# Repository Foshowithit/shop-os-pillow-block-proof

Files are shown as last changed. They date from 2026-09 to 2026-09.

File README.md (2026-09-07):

# Shop OS — Pillow-Block Proof

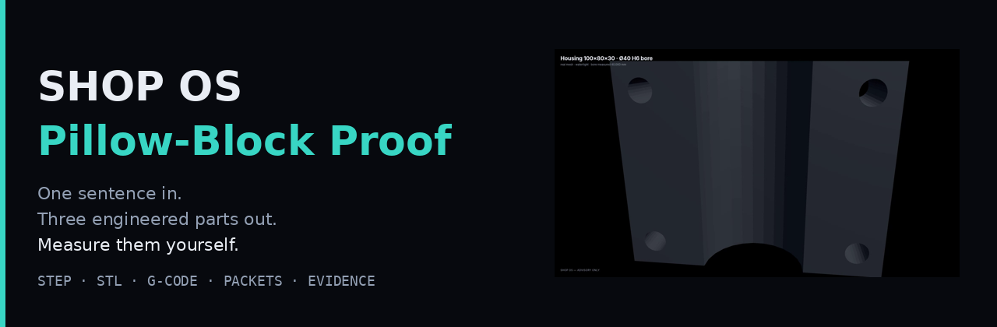
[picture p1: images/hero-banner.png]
Shop OS — Pillow-Block Proof


  

One sentence in. Three engineered parts out. **Measure them yourself.**

> Full run (28 s): one click → agent run → live interactive 3D part card in chat.
> Watch: [shopos-hero-28s.mp4](https://github.com/Foshowithit/shop-os-pillow-block-proof/releases/download/v1.0-proof/shopos-hero-28s.mp4)

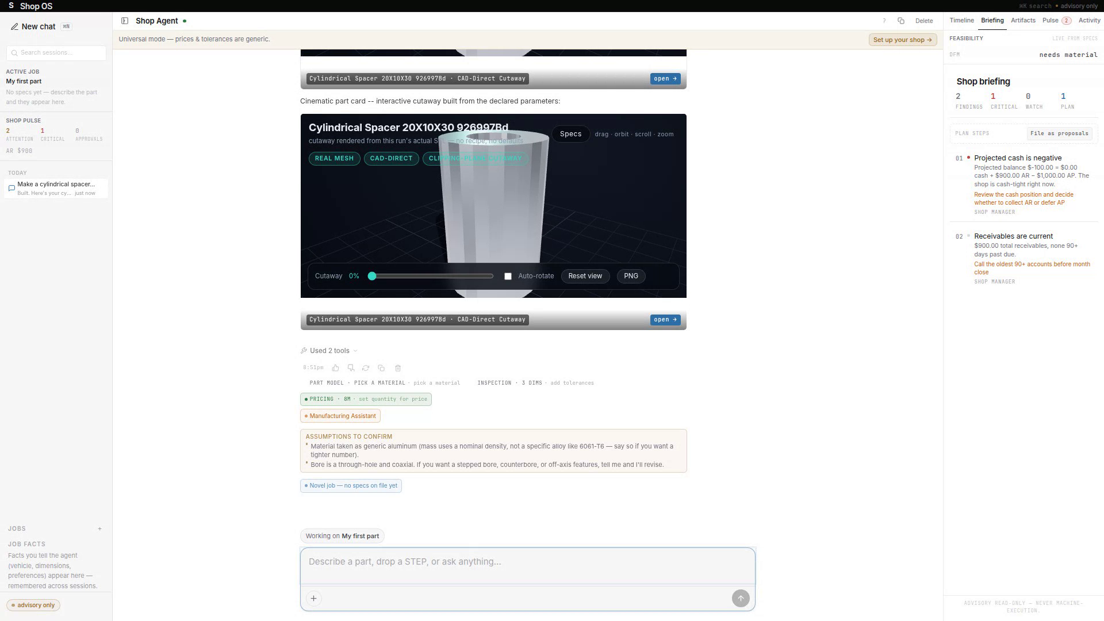
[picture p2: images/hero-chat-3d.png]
Live 3D part card inside the chat


> Full arc (78 s): run → housing orbit → spacer cutaway.
> Watch: [pillow-block-78s.mp4](https://github.com/Foshowithit/shop-os-pillow-block-proof/releases/download/v1.0-proof/pillow-block-78s.mp4)

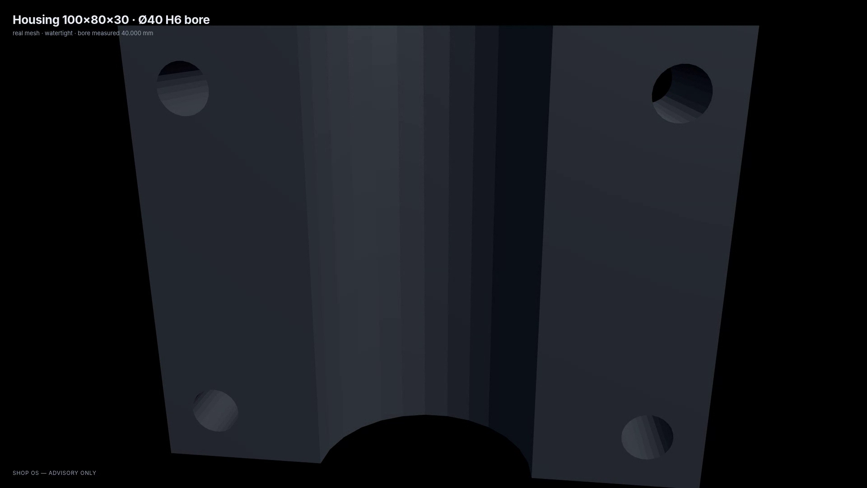
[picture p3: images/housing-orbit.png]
Housing 100×80×30, Ø40 H6 bore, orbiting


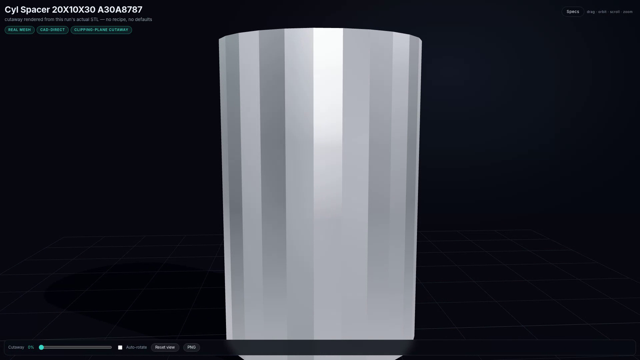
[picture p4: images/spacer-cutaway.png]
Spacer clipping-plane cutaway on the real mesh

> Beauty pass (30 s): orbit + cutaway.
> Watch: [shopos-card3d-30s.mp4](https://github.com/Foshowithit/shop-os-pillow-block-proof/releases/download/v1.0-proof/shopos-card3d-30s.mp4)

A shop agent takes a part description, engineers it (CAD, DFM, toolpaths,
verification), and hands you files — not renders. This repo is the receipts
from one real run: a pillow-block bearing unit (housing + cap + base plate).

## Watch

| Video | What |
|---|---|
| [shopos-hero-28s.mp4](https://github.com/Foshowithit/shop-os-pillow-block-proof/releases/download/v1.0-proof/shopos-hero-28s.mp4) | One click → agent run → live interactive 3D part card inside the chat (28 s) |
| [pillow-block-78s.mp4](https://github.com/Foshowithit/shop-os-pillow-block-proof/releases/download/v1.0-proof/pillow-block-78s.mp4) | Full arc: run → housing orbit → spacer cutaway (78 s) |
| [shopos-card3d-30s.mp4](https://github.com/Foshowithit/shop-os-pillow-block-proof/releases/download/v1.0-proof/shopos-card3d-30s.mp4) | Pure 3D: orbit + clipping-plane cutaway on the real mesh (30 s) |

## Measure it yourself

| File | Verification (independently re-measured) |
|---|---|
| `models/housing.step` / `.stl` | Open CASCADE 7.9 AP214 · 500 facets · watertight · bbox 100×80×30 · bore Ø40.000 |
| `models/cap.step` / `.stl` | 500 facets · watertight · groove Ø40.000 |
| `models/base_plate.step` / `.stl` | 876 facets · watertight · 120×100×12 |
| `programs/bore_h6_advisory.nc` | 113 blocks; parses clean; simulated — 36,224 voxels removed (1 mm grid) |
| `programs/drill_9mm.nc` | 11 blocks, 4×Ø9 pattern; simulated — 5,584 voxels removed |
| `programs/tap_m8.nc` | 14 blocks, M8×1.25 tapping w/ pitch check; simulated — 2,792 voxels removed |
| `programs/BLOCK-receipt.json` | Our own validator **refused** the naive end-mill-only Ø40 H6 plan |
| `programs/PASS-receipt.json` | Corrected bore+hone+CMM plan passes, hazard honestly still flagged |
| `verifiers/verify_pillow_block.py` | Runnable mesh verifier — `python verifiers/verify_pillow_block.py` from a clean clone |
| `validators/validate_tolerance_risk.py` | Runnable **manufacturing-plan risk linter** — reproduces BLOCK (exit 1) / PASS (exit 0) from public job cards |
| `validators/REPRODUCE.md` | Exact clean-clone commands and expected output |
| `packets/` | Per-part DFM packets + assembly manifest — every number reproduced; estimates labeled as estimates |

## Evidence class

- **Geometry-verified:** the three STL meshes pass the published watertight/bounding-box/bore verifier.
- **Process-reviewed:** the public RUE-019 manufacturing-plan linter reproduces the BLOCK→PASS verdicts.
- **Strategy-simulated:** the advisory NC programs are parser/stock-simulation inputs; they are **not** posted CAM, machine-kinematics verified, or production-approved.
- **Not yet proven:** machine capability, postprocessor output, physical machining, CMM/metrology, bearing selection from a cited catalog, and a production design load case.

## The honest flex

Most demos show success paths. Ours shows the system catching itself: the
naive bore plan gets BLOCKed with reasons, re-simulated as proof, and only
the corrected plan ships. Independently reviewed file-by-file — verdict: legit.

> ⚠️ **ADVISORY ONLY — NOT FOR MACHINE EXECUTION.** Every program, packet,
> and receipt here is engineering output for human review. Nothing runs on a
> controller without a qualified machinist's sign-off.

MIT License — files are yours to open, measure, cut (after review), and post about.

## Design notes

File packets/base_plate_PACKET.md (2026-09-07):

# Part Packet — Base Plate (pillow-block mounting plate)

_ADVISORY ONLY — machine_execution=false. No controller connection. No production authorization. Qualified machinist review required. No costs are stated in this packet (none computed). No cycle times are stated (none computed)._

## What this part is

Flat mounting plate the housed bearing bolts to: 120 × 100 × 12 slab
with four Dia 9 corner mounting holes and two M8×1.25 tapped holes.
No tight-tolerance bore on this part — general tolerance ±0.1 governs.

## Measured geometry (programmatic, not eyeballed)

Source: `verify_pillow_block.py` run 2026-09-07 — ALL PASS.

| Attribute | Measured |
|---|---|
| Envelope (bbox) | 120.00 × 100.00 × 12.00 mm |
| Mesh | watertight=True, 876 facets |
| Mesh volume | 138,586.7 mm³ (mesh volume, not weighed) |

Files: `base_plate.step` (44,473 B), `base_plate.stl` (43,884 B).

Note: the verifier checks envelope/watertight only for this part (no
bore feature). Hole diameters and positions below are program-stated,
not mesh-measured.

## DFM notes

- Straightforward 2.5D plate work: face, drill, tap. No validator
  hazard on this part (the H6/Ra-0.8 hazard lives on the housing/cap
  bore, not here).
- 12 mm plate in pre-hardened 4140 (job-spec material context): clamp
  flat, watch for movement after breaking the skin — shop practice,
  machinist to confirm.
- Tapped M8×1.25 in 12 mm plate gives ~9–10 mm thread engagement:
  adequate for a mounting plate, verify against the actual bolt loads
  (engineering check, not computed here).

## Process routing (plain English)

- `programs/drill_9mm.nc`: four Dia 9 corner holes at 15 mm insets
  (15,15 / 105,15 / 15,85 / 105,85), canned G81 cycle, Z−2 through,
  R14 retract. Positions are stated in the program header as an
  engineering assumption — confirm against the mating footprint.
- `programs/tap_m8.nc`: two M8×1.25 holes at (30,50) and (90,50) —
  Dia 6.8 drill (G81) then G84 tap at S800. Positions likewise assumed;
  confirm before cutting.

## Assumptions (estimates, not verified facts)

- All six hole positions are program-header assumptions, explicitly
  marked "(positions assumed - engineering assumption)" in the .nc
  files. They are not measured from the mesh and not approved.
- What the drill/tap programs IS: strategy/sequence proofs (hole order,
  canned cycles, tap pitch consistency), verified in sim (holes clear,
  lands kept, in-envelope SHIP). What they are NOT: posted, proven CAM
  — no post-processor ran and no machine kinematics were checked.
- Feeds/speeds (F180/F150/F1000, S800/S1200/S1500) are reference values;
  prove on the machine.

## Verification

- Geometry: `verify_pillow_block.py` PASS (watertight, bbox exact).
- Holes: program text reviewed only; hole callouts are NOT mesh-verified.

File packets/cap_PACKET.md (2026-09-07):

# Part Packet — Cap (pillow-block top half)

_ADVISORY ONLY — machine_execution=false. No controller connection. No production authorization. Qualified machinist review required. No costs are stated in this packet (none computed). No cycle times are stated (none computed)._

## What this part is

Upper half of the pillow-block housing. Mirrors the housing saddle with
a matching Dia 40 groove so the closed assembly traps the bearing race.
Same job spec family as the housing (4140 pre-hardened context,
general tolerance ±0.1 unless noted).

## Measured geometry (programmatic, not eyeballed)

Source: `verify_pillow_block.py` run 2026-09-07 — ALL PASS.

| Attribute | Measured |
|---|---|
| Envelope (bbox) | 100.00 × 80.00 × 20.00 mm |
| Groove diameter | 40.000 mm (span X 39.988, 28 bore-surface verts) |
| Mesh | watertight=True, 500 facets |
| Mesh volume | 106,759.3 mm³ (mesh volume, not weighed) |

Files: `cap.step` (37,360 B), `cap.stl` (25,084 B).

## Meshing note (from the verifier, factual)

The groove tool center sits 0.5 below the mating face (0.5 blind cover):
a nominal R20-on-20-thick tangency is a zero-thickness kiss that cannot
triangulate watertight. Groove diameter stays exactly 40.0; only the
cover overlap changed. This is a mesh-construction fact, not a design
change — the mating interface still closes on the housing saddle.

## DFM notes (grounded in validator receipts)

- The cap groove forms the top half of the Dia 40 H6 bore: same
  0.016 mm band + Ra 0.8 hazard as the housing (see housing packet and
  rue019 receipts). Same required controls apply — multi-pass,
  tolerance-capable tooling, runout budget, hone, CMM.
- Mating faces (cap-to-housing split line) must be flat and clean or
  the assembled bore distorts: face-mill both halves' split faces in
  the same setup family where possible (shop practice, machinist to
  confirm — not validator-stated).

## Process routing (plain English)

Same saddle program family as the housing
(`programs/bore_h6_advisory.nc` pattern: rough r=19.0 → semi r=19.7 →
finish r=20.0 → spring pass → hone → CMM), mirrored to the cap's 20 mm
thickness. What that program IS: a strategy/sequence proof (see housing
packet). What it is NOT: posted, proven CAM for the cap — no separate
cap program exists in `programs/`, and none is claimed here.

## Assumptions (estimates, not verified facts)

- Cap bolt circle / bolt sizes are not modeled and not specified: the
  cap-to-housing and cap-to-base fastening scheme is open engineering.
- Feeds/speeds, if reused from the housing program, are reference
  values; prove on the machine.

## Verification

- Geometry: `verify_pillow_block.py` PASS line (groove 40.000, span
  39.988 within the 0.6 mesh tolerance).
- Tolerance planning: inherits the rue019-corrected PASS approach;
  cap-specific validator run is open work, not claimed here.

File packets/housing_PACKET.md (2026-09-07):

# Part Packet — Housing (pillow-block saddle)

_ADVISORY ONLY — machine_execution=false. No controller connection. No production authorization. Qualified machinist review required. No costs are stated in this packet (none computed). No cycle times are stated (none computed)._

## What this part is

Lower half of a two-piece pillow-block bearing housing. A semicircular
saddle groove (nominal Dia 40 along the Y axis) cradles the bearing outer
race; the cap closes it from above. Material per job spec: 4140 alloy
steel, pre-hardened. General tolerance ±0.1 unless noted.

## Measured geometry (programmatic, not eyeballed)

Source: `verify_pillow_block.py` run 2026-09-07 — ALL PASS.

| Attribute | Measured |
|---|---|
| Envelope (bbox) | 100.00 × 80.00 × 30.00 mm |
| Saddle groove diameter | 40.000 mm (span X 40.000, 28 bore-surface verts) |
| Groove axis | X=50, Z=30, along Y, length 0–80 |
| Mesh | watertight=True, 500 facets |
| Mesh volume | 182,662.4 mm³ (mesh volume, not weighed) |

Files: `housing.step` (37,242 B), `housing.stl` (25,084 B).

## Critical feature — Dia 40 H6 bore

Spec (both rue019 job.yamls): diameter 40.0, +0.016/−0.000 (H6),
surface finish Ra 0.8. Tolerance band 0.016 mm — under the validator's
0.050 mm tight-band threshold — so this bore is the assembly's
tolerance hazard. See `rue019-block/` vs `rue019-corrected/` receipts
and the bore story in `ASSEMBLY.md`.

## DFM notes (grounded in validator receipts)

- A standard drill/ream cycle cannot hold H6 at 0.016 mm band + Ra 0.8
  (rue019-block BLOCK: "the card lacks a complete process response").
- Required, per receipt: multi-pass plan (rough → semi-finish → finish,
  spring pass optional), tolerance-capable tooling (fine boring head /
  adjustable reamer / honing — never a standard reamer without a
  capability check), runout budgeted against the 0.016 band, finish
  passes planned to Ra 0.8, CMM qualification.
- Saddle is an open half-round milled from above (not a closed bore):
  the corrected plan answers with profile passes + hone to size.

## Process routing (plain English)

Program `programs/bore_h6_advisory.nc` (advisory reference only):
 What this program IS: a strategy and sequence proof — the pass order,
 tool choices, and geometry a bore+hone+CMM plan needs, verified in sim
 (groove clears, stock kept, in-envelope SHIP).
 What it is NOT: posted, proven CAM. No post-processor ran, no machine
 kinematics were checked, feeds/speeds are reference values.
 datum is the housing base (Z0) with the X0Y0 corner; tools T1 D12 flat
 rougher and T2 D6 ball finisher. Four lanes across Y (10/30/50/70) cut
 the groove in three radii — rough r=19.0, semi r=19.7, finish r=20.0 —
 then a slow spring pass repeats the finish lane at Y40. To size means
 hone Dia 40 holding the 0.016 band, then CMM-qualify bore diameter
 (true position: none on this job).

## Assumptions (estimates, not verified facts)

- Stock 100×80×30 and 4140 pre-hardened come from the job spec, not from
  measurement of bar stock.
- Feeds/speeds in the .nc (F240/F120, S3000) are reference values from
  the advisory program; prove them on the machine, do not trust them.

## Verification

- Geometry: `verify_pillow_block.py` PASS line quoted above.
- Tolerance planning: rue019-corrected PASS (`response.adequate: true`,
  `missing: []`); the naive variant honestly BLOCKs (see ASSEMBLY.md).

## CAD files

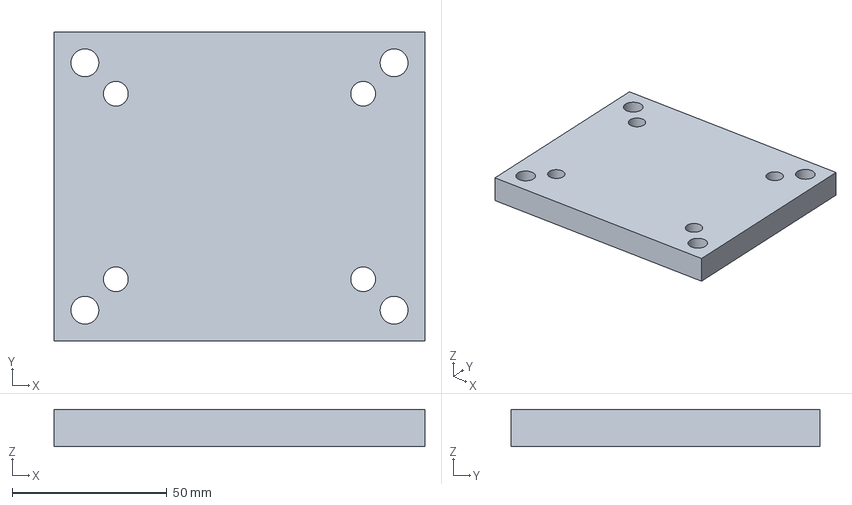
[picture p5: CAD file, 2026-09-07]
models/base_plate.step
120.0 x 100.0 x 12.0 mm

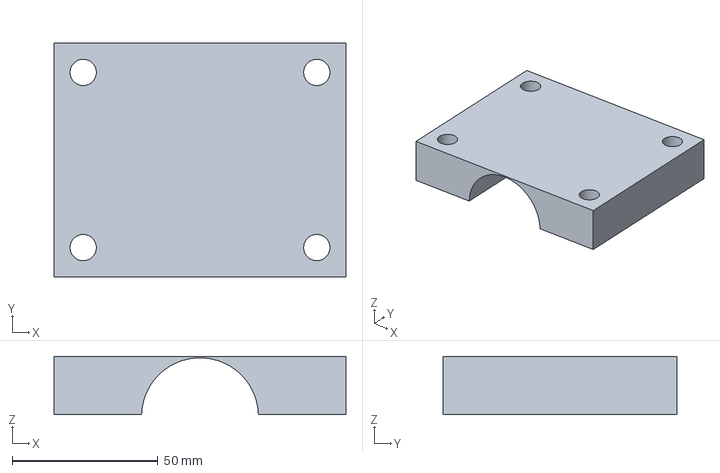
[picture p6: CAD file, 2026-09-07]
models/cap.step
100.0 x 80.0 x 20.0 mm

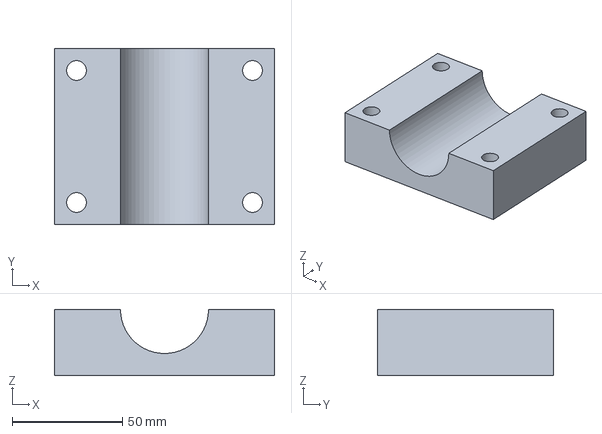
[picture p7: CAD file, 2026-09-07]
models/housing.step
100.0 x 80.0 x 30.0 mm

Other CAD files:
models/base_plate.stl
models/cap.stl
models/housing.stl

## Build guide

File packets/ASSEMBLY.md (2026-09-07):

# Pillow-Block Assembly Manifest (STAGE 3)

_ADVISORY ONLY — machine_execution=false. No controller connection. No production authorization. Qualified machinist review required. This manifest describes files; it authorizes nothing._

Assembly: two-piece pillow-block bearing housing (housing + cap,
Dia 40 H6 saddle bore) on a 120×100×12 mounting plate. Material context
per job spec: 4140 alloy steel, pre-hardened. No costs, no cycle times
anywhere in this stage (none computed).

## File manifest — what each file is + how it was verified

| File | What it is | How verified |
|---|---|---|
| `housing.step` / `housing.stl` | Housing solid + mesh (100×80×30, saddle Ø40) | `verify_pillow_block.py` PASS: watertight, 500 facets, bbox exact, bore 40.000 |
| `cap.step` / `cap.stl` | Cap solid + mesh (100×80×20, groove Ø40) | Verifier PASS: watertight, 500 facets, groove 40.000 (span 39.988 ≤ 0.6 tol); 0.5 blind-cover mesh note |
| `base_plate.step` / `base_plate.stl` | Mounting plate solid + mesh (120×100×12) | Verifier PASS: watertight, 876 facets, bbox exact (holes program-stated, not mesh-measured) |
| `verify_pillow_block.py` | Geometry checker (watertight/facets/volume/bbox/bore Ø40±0.6) | Ran 2026-09-07 via `.venv/bin/python`: ALL PASS (output quoted in packets) |
| `programs/bore_h6_advisory.nc` | 3-radius saddle program (rough 19.0 / semi 19.7 / finish 20.0 + spring) + hone/CMM notes | Header-stamped advisory-only; text-reviewed against corrected plan (multi-pass + hone + CMM present) |
| `programs/drill_9mm.nc` | 4× Dia 9 corner holes, G81 | Header-stamped advisory-only; positions explicitly assumed — confirm before cutting |
| `programs/tap_m8.nc` | 2× M8×1.25 (6.8 drill + G84 tap) | Header-stamped advisory-only; positions explicitly assumed — confirm before cutting |
| `rue019-block/job.yaml` | Naive plan input (Ø40 H6, Ra 0.8, "20mm end mill only") | Spec input to validator; drives the honest BLOCK |
| `rue019-block/tolerance-risk-validation.json` + `.md` | BLOCK receipt (`result: BLOCK`, `adequate: false`, missing tooling) | Validator-generated 2026-09-07; reason + 5 required controls quoted in housing packet |
| `rue019-corrected/job.yaml` | Corrected plan input (multi-pass, boring head/runout 0.005, reamer, hone, CMM) | Spec input to validator; drives the PASS |
| `rue019-corrected/tolerance-risk-validation.json` + `.md` | PASS receipt (`result: PASS`, `adequate: true`, `missing: []`) | Validator-generated 2026-09-07; hazard still True (correct — hazard persists, response adequate) |
| `housing_PACKET.md` / `cap_PACKET.md` / `base_plate_PACKET.md` | Per-part packets (this stage) | Numbers transcribed from verifier/validator outputs above — no invented values |
| `ASSEMBLY.md` | This manifest | Transcription of the same outputs |

All validator JSONs carry `machine_execution: false`,
`production_authorization: false`, `qualified_machinist_review_required: true`.

## Bore story: BLOCK → PASS (reads as a story)

1. **Naive plan fails honestly.** `rue019-block/job.yaml` answers a
   Ø40 H6 / 0.016-band / Ra-0.8 bore with "rough + finish with 20 mm
   end mill only." The validator finds the markers rough/finish/
   surface_finish present but the one thing that matters missing —
   tolerance-capable tooling — and BLOCKs with five required controls
   instead of waving it through.
2. **Corrected plan passes with proof.** `rue019-corrected/job.yaml`
   answers every control: rough/semi-finish/finish + spring pass, fine
   boring head with 0.005 runout budget, adjustable reamer, hone to
   size, CMM qualification with true-position check. The validator
   returns PASS with `missing: []` — while keeping `hazard: True`,
   which is the honest shape: the tolerance risk is real, and this
   plan covers it. Advisory review still required either way.

## Open work (not claimed)

- No cap-specific validator run; no cap-specific .nc program.
- Base-plate hole positions/threads are program assumptions, unapproved.
- No costs, no cycle times, no feeds/speeds proven — all open.
- Plain version of the above: every .nc here IS a strategy and sequence
  proof (what order, what tools, what geometry — checked in sim); none
  of them IS posted, proven CAM (no post-processor, no machine kinematics,
  nothing here runs a spindle).

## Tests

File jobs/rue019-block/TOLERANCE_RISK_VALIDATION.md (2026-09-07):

# Tight-Tolerance Bore Validation

**Result:** BLOCK
**Hazard:** True
**Tight grades:** h6
**Tightest band:** 0.016 mm
**Surface finish Ra:** 0.8 um
**True position:** None mm

Tight-tolerance process gap: tight ISO grade (h6); tolerance band 0.016 mm (< 0.050 mm); surface finish Ra 0.8 (<= 0.8). A standard drill/ream cycle cannot hold this tolerance — the card lacks a complete process response. Missing: tolerance-capable tooling (fine boring / adjustable reamer / honing). Recommend rough -> semi-finish -> finish (spring pass optional), fine-boring/adjustable-reamer tooling, runout budget vs the tolerance band, and surface-finish planning.

**Required controls:**
- detect tight ISO tolerance grades (H6 / H5 / H4) on bores/shafts and escalate to a multi-pass process plan (rough -> semi-finish -> finish, optional spring pass)
- verify selected tooling can hold the tolerance (fine boring head, adjustable reamer, or honing — never a standard reamer without capability check)
- flag surface-finish requirements (Ra <= 0.8 um) and plan finish passes to meet them
- budget tool runout against the tolerance band and flag if the machine/spindle cannot reasonably hold it
- respect true-position callouts (<= 0.05 mm) with a location/qualification strategy (datum bore reaming, probing)

_ADVISORY ONLY — machine_execution=false. No controller connection. No production authorization. Qualified machinist review required._

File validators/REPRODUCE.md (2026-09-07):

# Reproduce it yourself

From a clean clone of this repo, with any Python 3.10+ that has
`numpy`, `trimesh`, and (optional, degrades gracefully) `pyyaml`:

```bash
pip install numpy trimesh
```

## 1. Model verification (STLs)

```bash
python verifiers/verify_pillow_block.py
```

Expected output (exit 0):

```text
PASS housing: watertight=True facets=500 vol=182662.4mm3 bbox=(100.00,80.00,30.00) bore_dia=40.000 bore_span_x=40.000 n_borev=28
PASS cap: watertight=True facets=500 vol=106759.3mm3 bbox=(100.00,80.00,20.00) bore_dia=40.000 bore_span_x=39.988 n_borev=28
PASS base_plate: watertight=True facets=876 vol=138586.7mm3 bbox=(120.00,100.00,12.00)
ALL PASS
```

## 2. Tolerance validator (RUE-019)

`validators/validate_tolerance_risk.py` is a verbatim copy of the
deterministic source validator (stdlib only; `yaml` optional). It writes
`tolerance-risk-validation.json` + `.md` next to each job card:

```bash
python validators/validate_tolerance_risk.py jobs/rue019-block
echo "exit: $?"
# exit: 1  — result BLOCK (end-mill-only Ø40 H6 plan)

python validators/validate_tolerance_risk.py jobs/rue019-corrected
echo "exit: $?"
# exit: 0  — result PASS (bore + hone + CMM prescription)
```

Both receipts are checked into `jobs/` — re-running overwrites them
with identical verdicts (timestamps differ, verdicts don't).

## 3. Advisory programs

`programs/*.nc` are strategy/sequence proofs, not posted CAM (see the
packet IS/IS-NOT notes). They parse under any Fanuc-dialect reader that
accepts comments, G0/G1/G2/G3, G81/G84 cycles, and M30.

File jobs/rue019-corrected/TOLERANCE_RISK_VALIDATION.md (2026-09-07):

# Tight-Tolerance Bore Validation

**Result:** PASS
**Hazard:** True
**Tight grades:** h6
**Tightest band:** 0.016 mm
**Surface finish Ra:** 0.8 um
**True position:** None mm

Tight-tolerance hazard detected (H6 / tight band / Ra / true position) but the card plans for it: multi-pass finishing, tolerance-capable tooling, surface-finish / runout awareness. Advisory review still required.

**Required controls:**
- (none)

_ADVISORY ONLY — machine_execution=false. No controller connection. No production authorization. Qualified machinist review required._

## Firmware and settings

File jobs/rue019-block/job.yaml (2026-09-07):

material:
  name: "4140 Alloy Steel (pre-hardened)"
stock:
  width: 100.0
  depth: 80.0
  height: 30.0
tolerances:
  general: 0.1
  bore_h6:
    diameter: 40.0
    upper_deviation: 0.016
    lower_deviation: 0.000
    fit: "H6"
    surface_finish_ra: 0.8
features:
  critical_bore:
    diameter: 40.0
    depth: 80.0
    tolerance_grade: "H6"
    process_plan: "rough + finish with 20mm end mill only, full slot conventional"
response:
  tooling: "20 mm carbide end mill, single setup"

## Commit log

2026-09-07 Pillow-block proof: 3 parts, programs, packets, videos (verified)
    [base_plate.step, base_plate.stl, cap.step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]
2026-09-07 Make proof rerunnable: validator, verifier repair, spindle restart

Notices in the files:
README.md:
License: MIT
